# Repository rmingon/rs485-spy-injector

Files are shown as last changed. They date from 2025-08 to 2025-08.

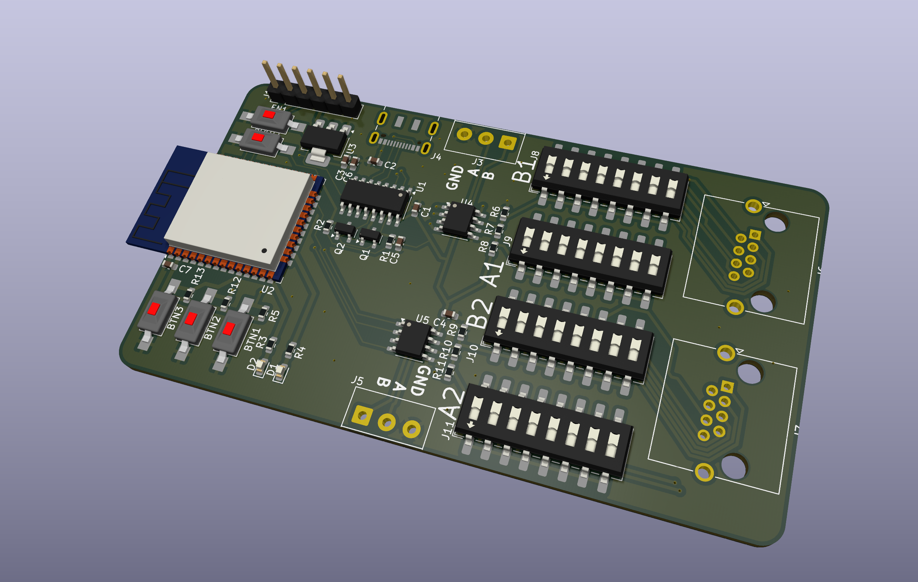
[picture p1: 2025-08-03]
3d.png

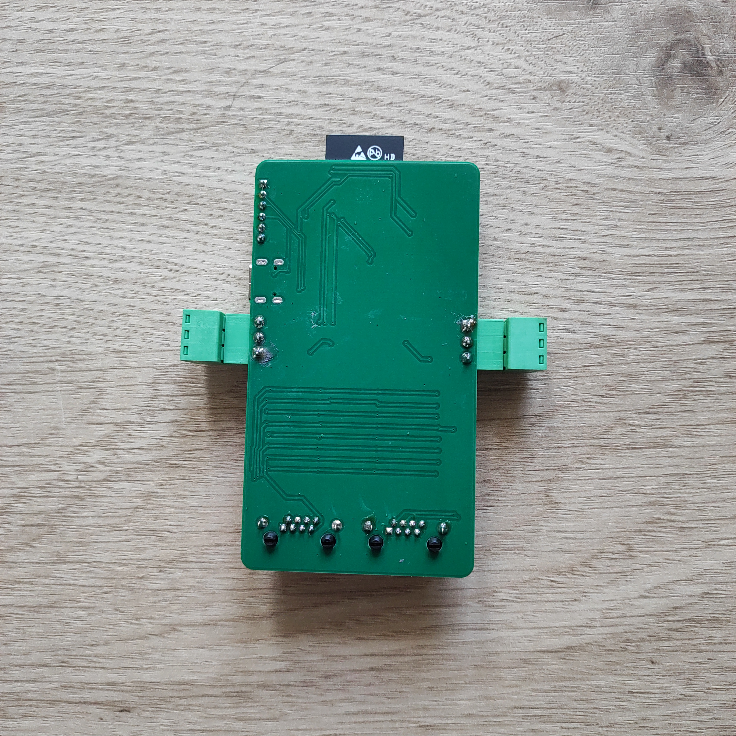
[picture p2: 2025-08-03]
back_pcb.jpg

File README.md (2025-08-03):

# ESP32 RS485 Hacker Suite

### _Sniff, Inject, and Control RS485 Communication from Your Phone_



## Overview

**ESP32 RS485 Hacker Suite** is a mobile-integrated toolkit built around the ESP32 microcontroller, designed to interact with RS485-based communication systems. This system allows for full control, inspection, and injection of RS485 traffic — making it a valuable asset for penetration testers, reverse engineers, and industrial system analysts.

## Features

- **RS485 Sniffing**  
  Monitor and log communication over RS485 in raw hex format. Useful for debugging, protocol analysis, or reverse engineering.

- **Hex Injection (Manual & Presets)**  
  Send custom hex data manually or use predefined presets. This supports use cases like device emulation, protocol fuzzing, or triggering specific system behaviors.

- **Mobile App Interface**  
  Control every feature directly from a smartphone via a dedicated app. Includes interfaces for configuration, command sending, and history review.

- **Dual RS485 Bus Support**  
  Work with two independent RS485 buses, ideal for simultaneously observing and injecting data into separate lines.

- **WiFi Configuration**  
  Easily connect your ESP32 to a local network or operate it in AP mode.

- **Command Presets**  
  Create and store frequently used hex commands for rapid execution.

- **Reception History**  
  View a log of all received data, enabling traffic inspection and replay.

## Ethical Hacking Applications

> **Important:** This tool is provided for **authorized use only**. Unauthorized access or tampering with industrial systems is illegal and unethical.

- Reverse engineering RS485-based protocols (MODBUS RTU, proprietary systems, etc.)
- Pen-testing building automation hardware (e.g., HVAC, elevator controllers, door access systems)
- Replay attacks or fault injection to test system resilience
- Simulating RS485 slave/master devices
- Forensic logging of unsecured RS485 data transmissions

## Hardware

- ESP32 (WROOM or S3 variant recommended)
- Dual RS485 transceivers (e.g., MAX485)
- Level shifters and protection diodes
- Power supply (USB or external)
- Custom PCB (designed in KiCad)

## Mobile App Overview

- Configure each RS485 bus individually
- Set baud rates and communication parameters
- Enter and send custom hex data manually
- Create named command presets (e.g., open door)
- View reception history for each bus

## Quick Example

```
Preset: Open door
Command: 09 21 32 AA B2
Target Device: Access Controller
Result: Relay Triggered, Door Unlocked
```

## Getting Started

### Flashing Firmware

1. Upload `main.cpp` to your ESP32 using Arduino IDE or PlatformIO.
2. Power on the device and connect via serial or mobile app.
3. Configure your RS485 settings and network preferences.

### Using the App

1. Connect to the ESP32 over WiFi.
2. Select Bus 1 or Bus 2.
3. Set the appropriate baud rate.
4. Send hex data manually or use a saved preset.
5. Monitor the reception log for data.

## Protocols Supported

- MODBUS RTU
- BACnet MS/TP (partial)
- Custom/Proprietary RS485 protocols
- Most serial-based building and industrial control protocols

## Disclaimer

This tool is meant for **educational, testing, and research** purposes only. Use it exclusively on systems you own or have explicit permission to test.

**You are fully responsible for how this tool is used. Unauthorized access or tampering with live systems can lead to legal consequences.**

5. **Use and Modify** the project under CERN-OHL v2 license.

## License

This project is licensed under the **CERN Open Hardware Licence Version 2**. See `LICENSE` file for full terms.

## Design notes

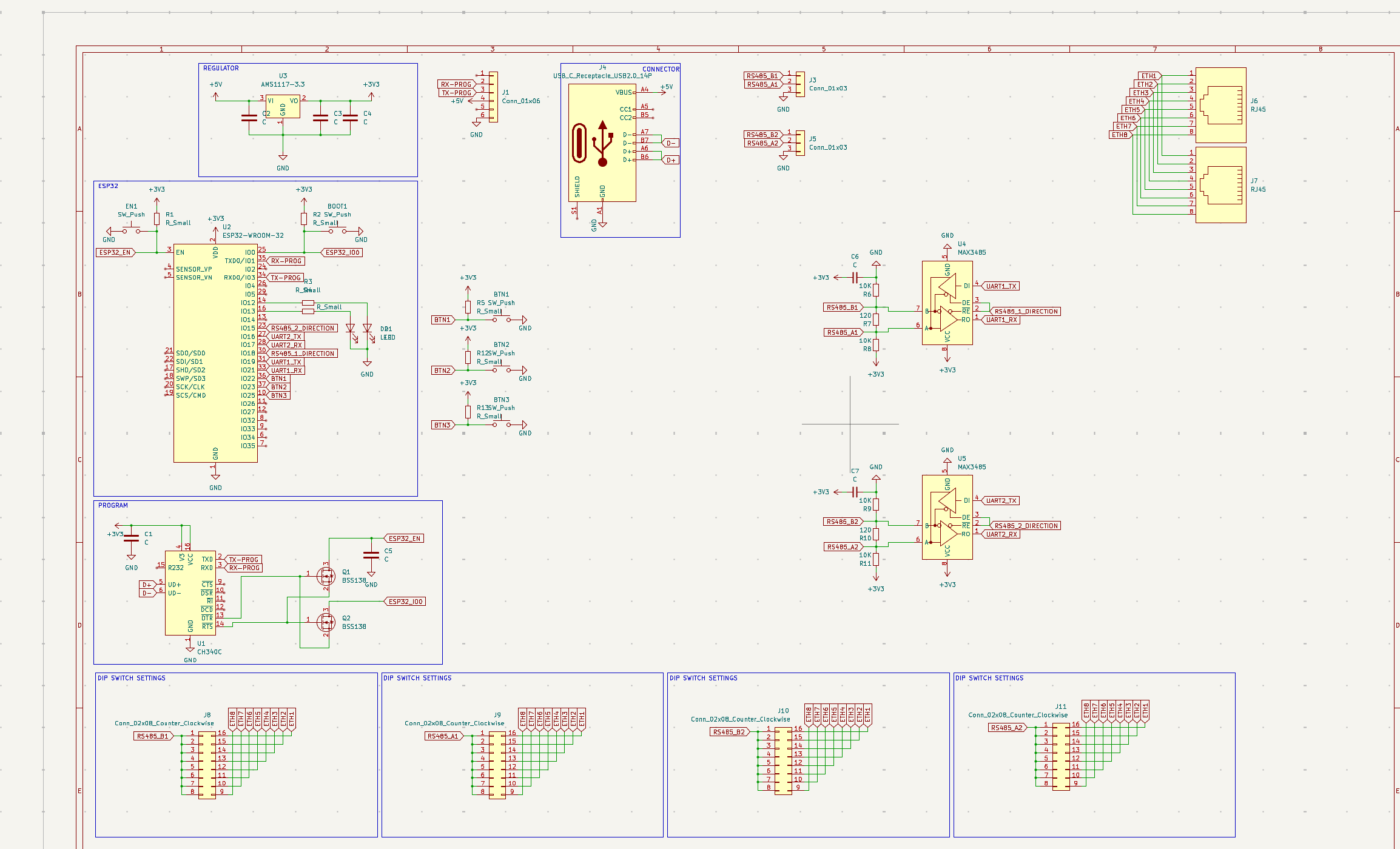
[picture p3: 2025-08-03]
schematic.png

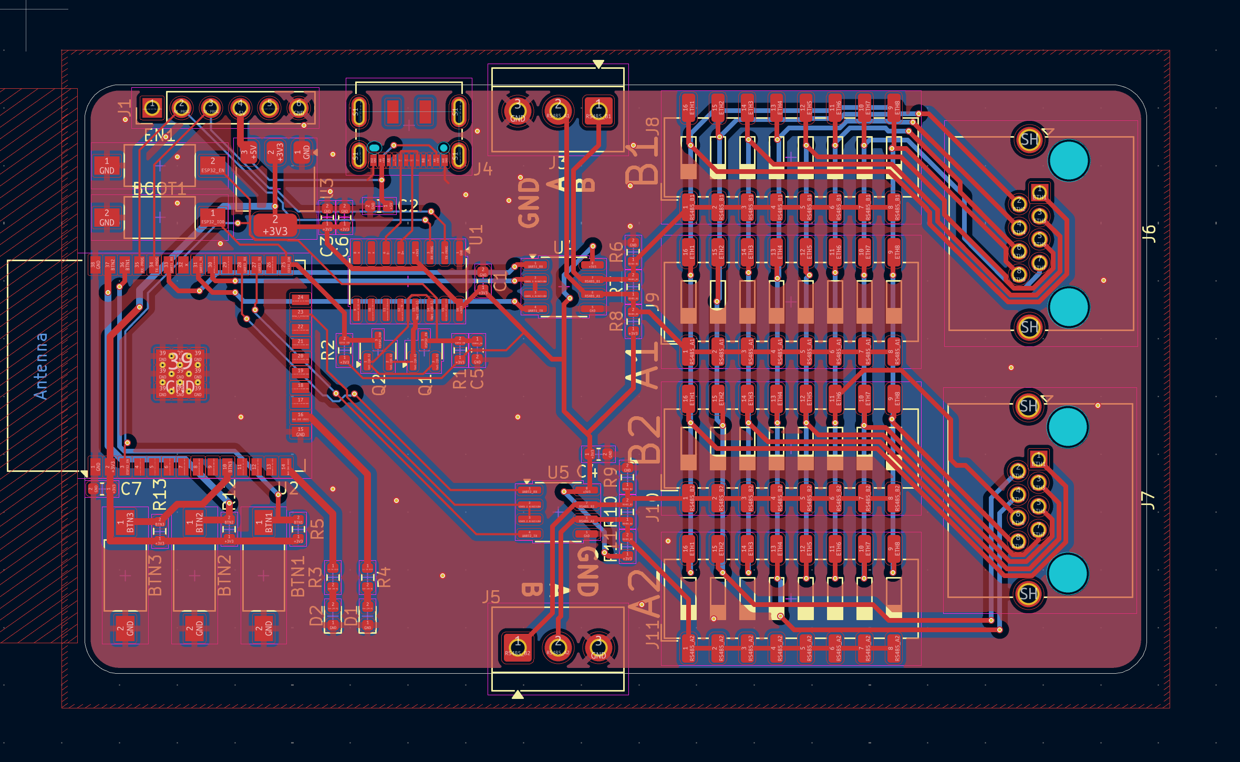
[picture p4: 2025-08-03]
pcb.png

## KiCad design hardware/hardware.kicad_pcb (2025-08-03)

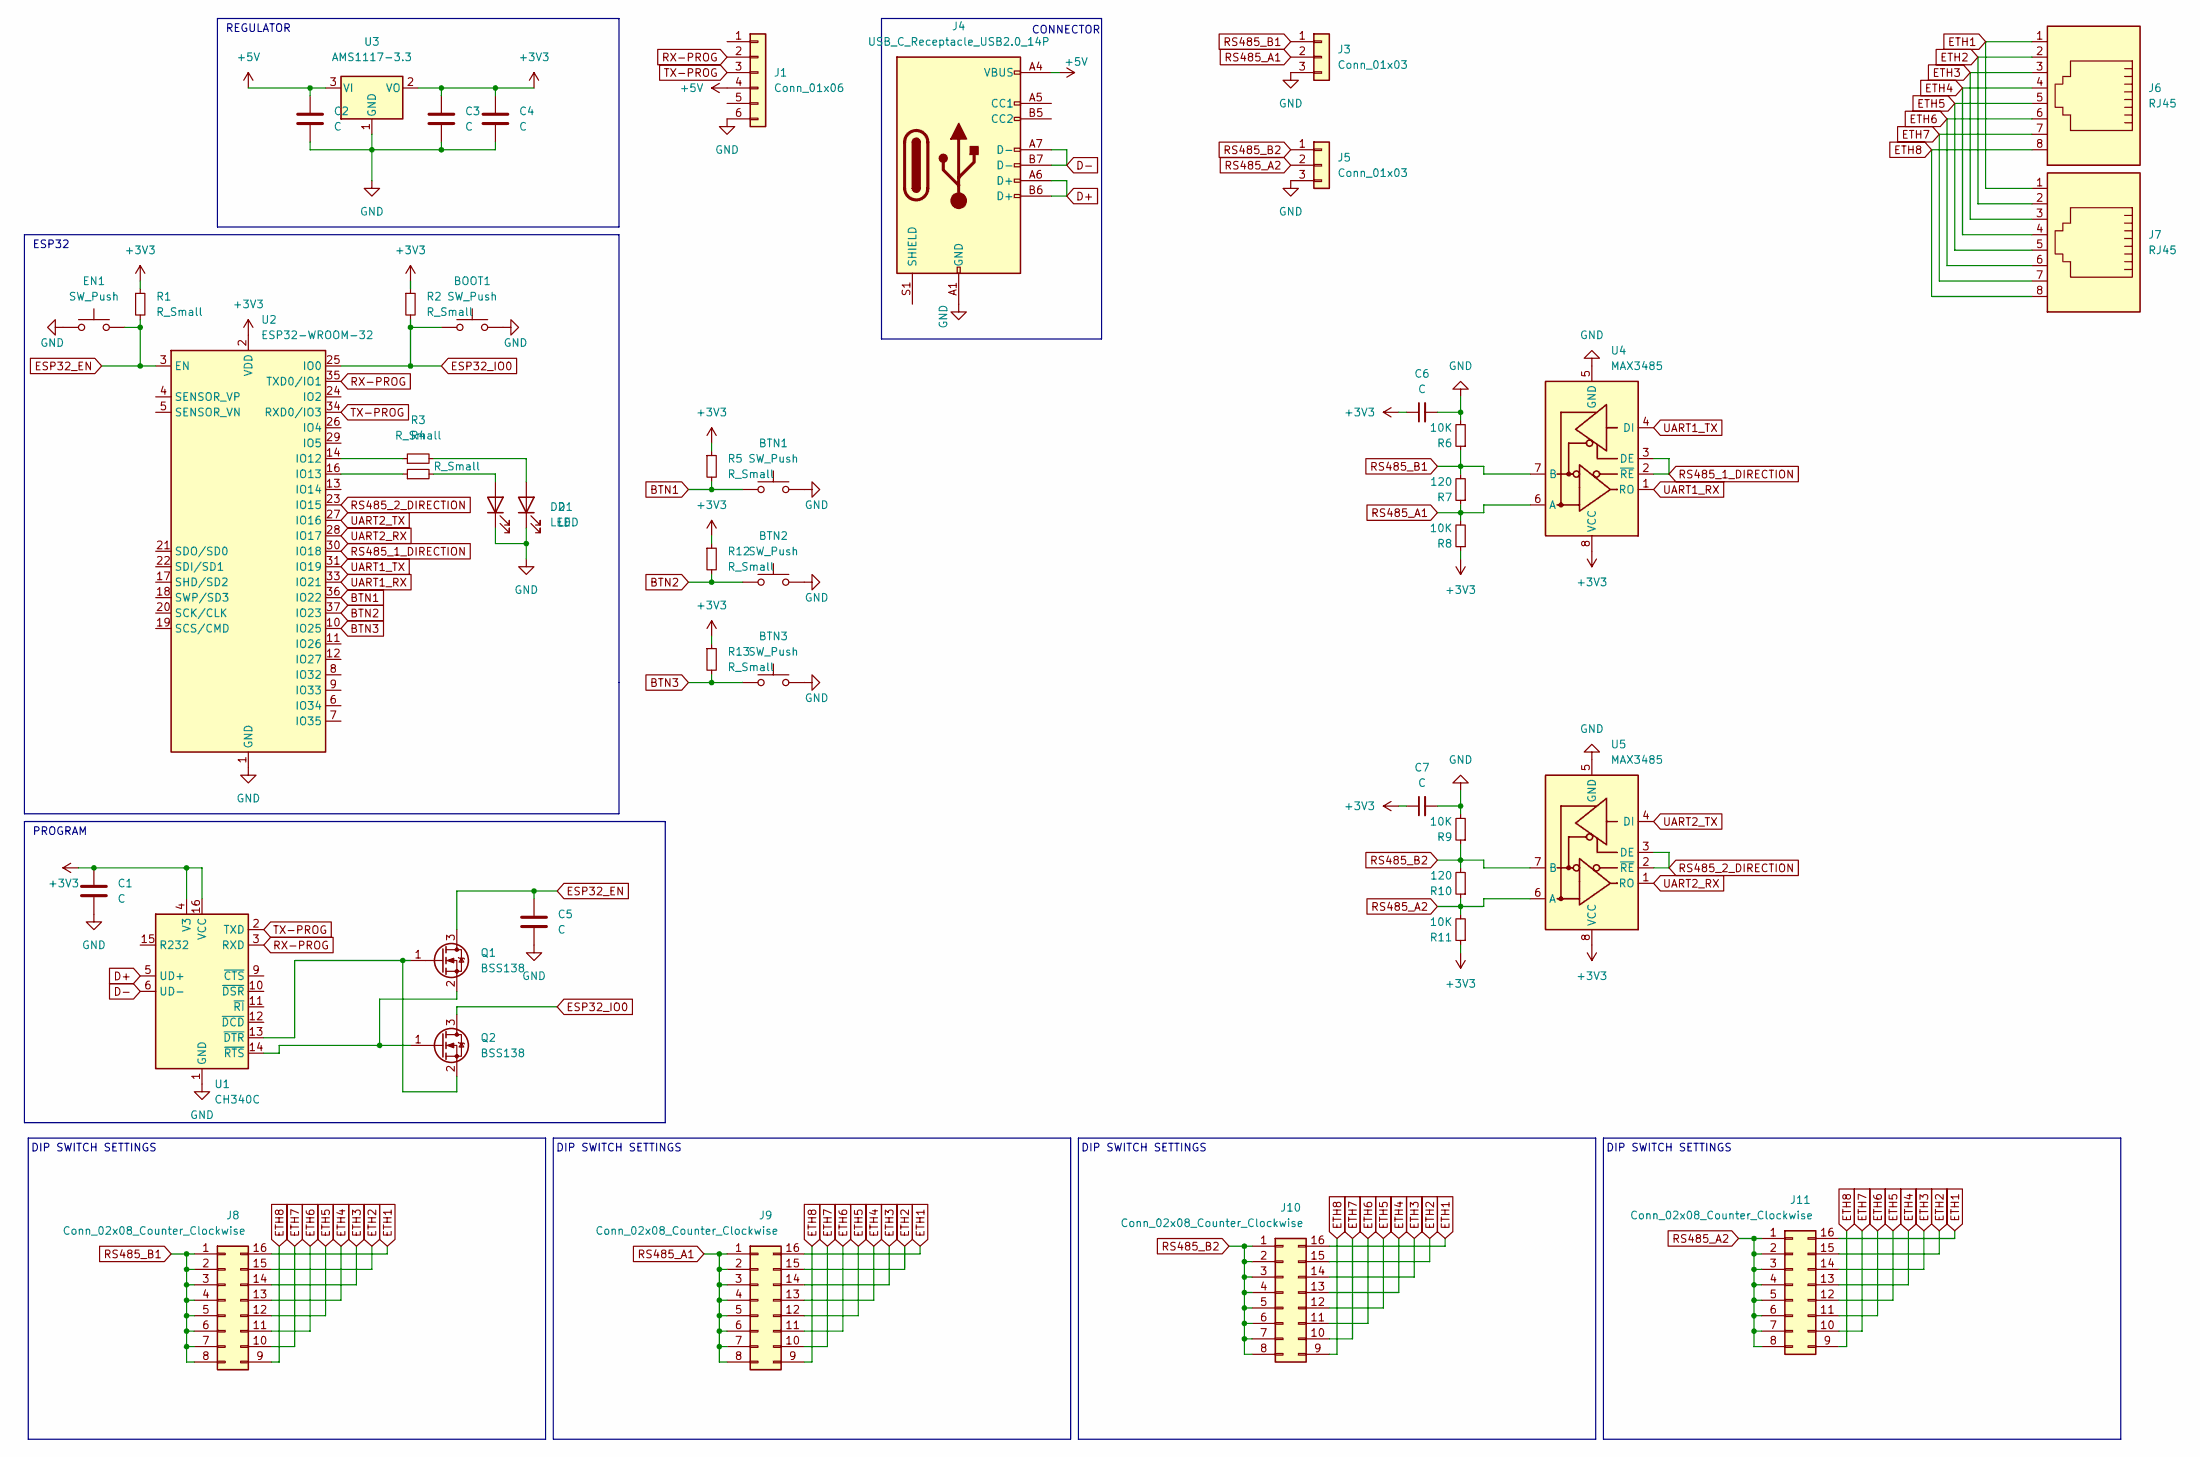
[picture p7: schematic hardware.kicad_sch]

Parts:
BOOT1: SW_Push; SW_SPST_FSMSM; LCSC C398053
BTN1, BTN2, BTN3: SW_Push; SW_SPST_FSMSM; LCSC C398053
C1, C2, C4: C; C_0603_1608Metric; LCSC C30926
C3, C5: C; C_0603_1608Metric; LCSC C19702
C6, C7: C; C_0603_1608Metric; LCSC C106245
D1: LED; LED_0603_1608Metric; LCSC C19171301
D2: LED; LED_0603_1608Metric; LCSC C434425
EN1: SW_Push; SW_SPST_FSMSM; LCSC C398053
J1: Conn_01x06; PinHeader_1x06_P2.54mm_Vertical
J3, J5: Conn_01x03; TerminalBlock_4Ucon_1x03_P3.50mm_Horizontal
J4: USB_C_Receptacle_USB2.0_14P; USB_C_Receptacle_JAE_DX07S016JA1R1500; LCSC C963213
J6, J7: RJ45; RJ45_Amphenol_RJHSE5380
J8, J9, J10, J11: Conn_02x08_Counter_Clockwise; SW_DIP_SPSTx08_Slide_6.7x21.88mm_W8.61mm_P2.54mm_LowProfile; LCSC C3293158
Q1, Q2: BSS138; SOT-23; LCSC C7420338
R1, R2, R5, R12, R13: R_Small; R_0603_1608Metric; LCSC C98220
R3, R4: R_Small; R_0603_1608Metric; LCSC C2906975
R6, R8, R9, R11: 10K; R_0603_1608Metric; LCSC C22975
R7, R10: 120; R_0603_1608Metric; LCSC C22975
U1: CH340C; SOIC-16_3.9x9.9mm_P1.27mm; LCSC C84681
U2: ESP32-WROOM-32; LCSC C82899
U3: AMS1117-3.3; SOT-223-3_TabPin2; LCSC C6186
U4, U5: MAX3485; SOIC-8_3.9x4.9mm_P1.27mm; LCSC C9943

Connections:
+3V3: C1.1, C3.1, C4.1, C6.1, C7.1, R1.1, R2.1, R5.1, R8.1, R11.1, R12.1, R13.1, U1.4 (V3), U1.16 (VCC), U2.2 (VDD), U3.2 (VO), U4.8 (VCC), U5.8 (VCC)
+5V: C2.1, J1.4, J4.A4 (VBUS), J4.A9 (VBUS), J4.B4 (VBUS), J4.B9 (VBUS), U3.3 (VI)
BTN1: BTN1.1, R5.2, U2.36 (IO22)
BTN2: BTN2.1, R12.2, U2.37 (IO23)
BTN3: BTN3.1, R13.2, U2.10 (IO25)
D+: J4.A6 (D+), J4.B6 (D+), U1.5 (UD+)
D-: J4.A7 (D-), J4.B7 (D-), U1.6 (UD-)
ESP32_EN: C5.1, EN1.2, Q1.3 (D), R1.2, U2.3 (EN)
ESP32_IO0: BOOT1.1, Q2.3 (D), R2.2, U2.25 (IO0)
ETH1: J6.1, J7.1, J8.16, J9.16, J10.16, J11.16
ETH2: J6.2, J7.2, J8.15, J9.15, J10.15, J11.15
ETH3: J6.3, J7.3, J8.14, J9.14, J10.14, J11.14
ETH4: J6.4, J7.4, J8.13, J9.13, J10.13, J11.13
ETH5: J6.5, J7.5, J8.12, J9.12, J10.12, J11.12
ETH6: J6.6, J7.6, J8.11, J9.11, J10.11, J11.11
ETH7: J6.7, J7.7, J8.10, J9.10, J10.10, J11.10
ETH8: J6.8, J7.8, J8.9, J9.9, J10.9, J11.9
GND: BOOT1.2, BTN1.2, BTN2.2, BTN3.2, C1.2, C2.2, C3.2, C4.2, C5.2, C6.2, C7.2, D1.1 (K), D2.1 (K), EN1.1, J1.6, J3.3, J4.A1 (GND), J4.A12 (GND), J4.B1 (GND), J4.B12 (GND), J5.3, R6.2, R9.2, U1.1 (GND), U2.1 (GND), U2.15 (GND), U2.38 (GND), U2.39 (GND), U3.1 (GND), U4.5 (GND), U5.5 (GND)
unnamed: D1.2 (A), R4.2
unnamed: D2.2 (A), R3.2
unnamed: Q1.1 (G), Q2.2 (S), U1.13 (~DTR)
unnamed: Q1.2 (S), Q2.1 (G), U1.14 (~RTS)
unnamed: R3.1, U2.14 (IO12)
unnamed: R4.1, U2.16 (IO13)
RS485_1_DIRECTION: U2.30 (IO18), U4.2 (~RE), U4.3 (DE)
RS485_2_DIRECTION: U2.23 (IO15), U5.2 (~RE), U5.3 (DE)
RS485_A1: J3.2, J9.1, J9.2, J9.3, J9.4, J9.5, J9.6, J9.7, J9.8, R7.1, R8.2, U4.6 (A)
RS485_A2: J5.2, J11.1, J11.2, J11.3, J11.4, J11.5, J11.6, J11.7, J11.8, R10.1, R11.2, U5.6 (A)
RS485_B1: J3.1, J8.1, J8.2, J8.3, J8.4, J8.5, J8.6, J8.7, J8.8, R6.1, R7.2, U4.7 (B)
RS485_B2: J5.1, J10.1, J10.2, J10.3, J10.4, J10.5, J10.6, J10.7, J10.8, R9.1, R10.2, U5.7 (B)
RX-PROG: J1.2, U1.3 (RXD), U2.35 (TXD0/IO1)
TX-PROG: J1.3, U1.2 (TXD), U2.34 (RXD0/IO3)
UART1_RX: U2.33 (IO21), U4.1 (RO)
UART1_TX: U2.31 (IO19), U4.4 (DI)
UART2_RX: U2.28 (IO17), U5.1 (RO)
UART2_TX: U2.27 (IO16), U5.4 (DI)

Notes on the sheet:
ESP32
CONNECTOR
DIP SWITCH SETTINGS
PROGRAM
REGULATOR

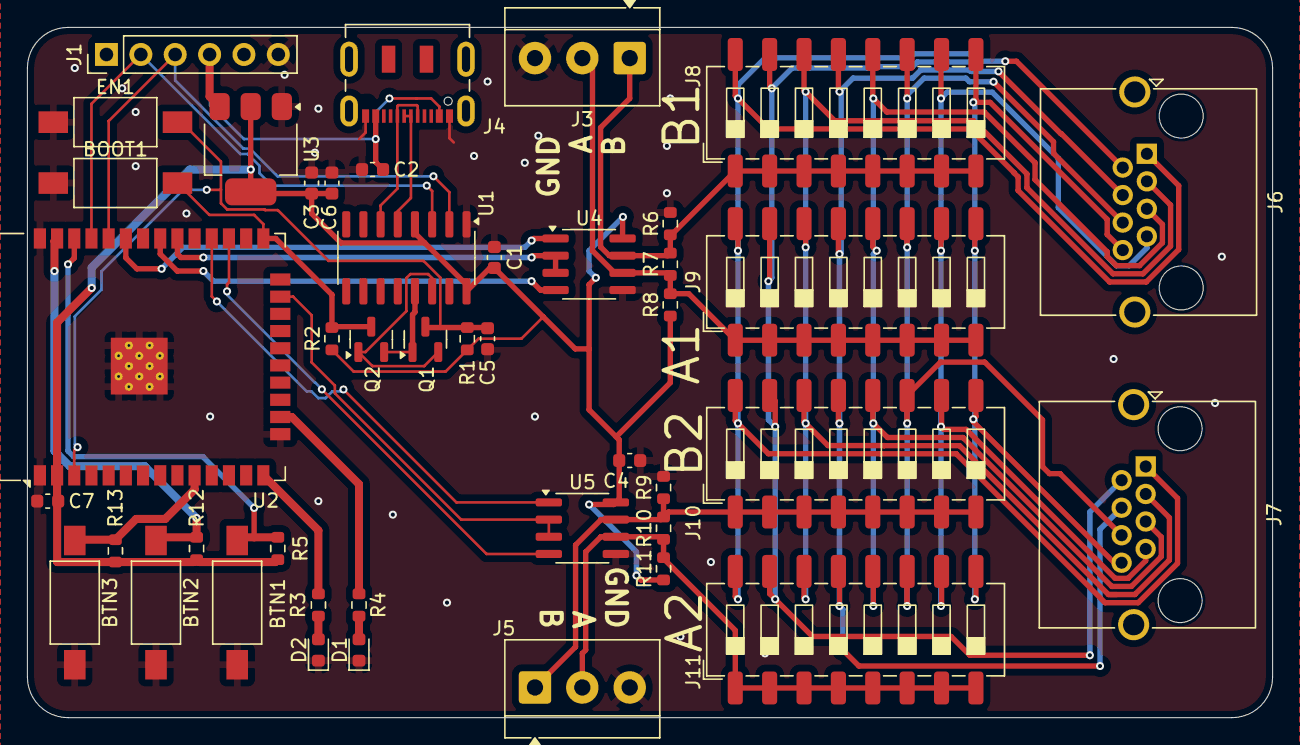
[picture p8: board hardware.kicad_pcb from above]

Board: 2 copper layers, 92.0 x 51.0 mm, 44 parts (0 on the bottom side), 36 nets.

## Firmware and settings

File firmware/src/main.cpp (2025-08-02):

#include <Arduino.h>
#include <ArduinoJson.h>
#include <BluetoothSerial.h>
#include <WiFi.h>
#include <vector>

static constexpr int UART1_RX = 21;
static constexpr int UART1_TX = 19;
static constexpr int UART2_RX = 17;
static constexpr int UART2_TX = 16;
static constexpr int RS485_DIR1 = 18;
static constexpr int RS485_DIR2 = 15;

static uint32_t UART1_BAUD = 115200;
static uint32_t UART2_BAUD = 115200;

BluetoothSerial SerialBT;

int tcpPort = 3333;
WiFiServer *tcpServer = nullptr;
WiFiClient tcpClient;

template <size_t N>
struct Ring
{
  volatile uint8_t buf[N];
  volatile size_t head = 0, tail = 0;
  volatile bool chunkReady = false;
  inline bool push(uint8_t b)
  {
    size_t n = (head + 1) % N;
    if (n == tail)
      return false; // Overflow
    buf[head] = b;
    head = n;
    return true;
  }
  size_t popMany(uint8_t *out, size_t maxBytes)
  {
    size_t cnt = 0;
    while (tail != head && cnt < maxBytes)
    {
      out[cnt++] = buf[tail];
      tail = (tail + 1) % N;
    }
    return cnt;
  }
  inline bool empty() const { return head == tail; }
};
static Ring<1024> rb1;
static Ring<1024> rb2;

static char btLine[512];
static size_t btLen = 0;
volatile bool btReady = false;
static char tcpLine[512];
static size_t tcpLen = 0;
volatile bool tcpReady = false;

static inline uint8_t hexVal(char c)
{
  if (c >= '0' && c <= '9')
    return c - '0';
  if (c >= 'a' && c <= 'f')
    return 10 + (c - 'a');
  if (c >= 'A' && c <= 'F')
    return 10 + (c - 'A');
  return 0xFF;
}
bool parseHexBytes(const char *s, std::vector<uint8_t> &out)
{
  uint8_t hn = 0xFF;
  for (; *s; ++s)
  {
    if (*s == ' ' || *s == ',' || *s == ':')
      continue;
    uint8_t v = hexVal(*s);
    if (v == 0xFF)
      continue;
    if (hn == 0xFF)
      hn = v;
    else
    {
      out.push_back((hn << 4) | v);
      hn = 0xFF;
    }
  }
  return hn == 0xFF;
}
String toHexLine(const uint8_t *data, size_t len)
{
  static const char *H = "0123456789ABCDEF";
  String s;
  s.reserve(len * 3);
  for (size_t i = 0; i < len; i++)
  {
    s += H[(data[i] >> 4) & 0xF];
    s += H[data[i] & 0xF];
    if (i + 1 < len)
      s += ' ';
  }
  return s;
}
void rs485SetDir(int pin, bool txOn) { digitalWrite(pin, txOn ? HIGH : LOW); }
void rs485Tx(int bus, const uint8_t *data, size_t len)
{
  HardwareSerial &U = (bus == 1) ? Serial1 : Serial2;
  int dirPin = (bus == 1) ? RS485_DIR1 : RS485_DIR2;
  rs485SetDir(dirPin, true);
  U.write(data, len);
  U.flush();
  rs485SetDir(dirPin, false);
}

void sendJsonToBT(const JsonDocument &d)
{
  serializeJson(d, SerialBT);
  SerialBT.print('\n');
}
void sendJsonToTCP(const JsonDocument &d)
{
  if (tcpClient && tcpClient.connected())
  {
    serializeJson(d, tcpClient);
    tcpClient.print('\n');
  }
}
void sendJsonToAll(const JsonDocument &d)
{
  sendJsonToBT(d);
  sendJsonToTCP(d);
}

void onUart1Rx()
{
  while (Serial1.available())
    rb1.push(Serial1.read());
  rb1.chunkReady = true;
}
void onUart2Rx()
{
  while (Serial2.available())
    rb2.push(Serial2.read());
  rb2.chunkReady = true;
}

void onBtData(const uint8_t *data, size_t len)
{
  for (size_t i = 0; i < len; i++)
  {
    if (btLen < sizeof(btLine) - 1)
      btLine[btLen++] = char(data[i]);
    if (data[i] == '\n')
    {
      btLine[btLen] = '\0';
      btReady = true;
    }
  }
}

bool wifiConnect(const char *ssid, const char *pwd, uint32_t timeoutMs = 8000)
{
  WiFi.mode(WIFI_STA);
  WiFi.begin(ssid, pwd);
  uint32_t t0 = millis();
  while (WiFi.status() != WL_CONNECTED && (millis() - t0) < timeoutMs)
  {
    delay(100);
  }
  return WiFi.status() == WL_CONNECTED;
}
void tcpStop()
{
  if (tcpClient)
  {
    tcpClient.stop();
  }
  if (tcpServer)
  {
    tcpServer->close();
    delete tcpServer;
    tcpServer = nullptr;
  }
}
bool tcpStart(int port)
{
  tcpStop();
  tcpServer = new WiFiServer(port);
  tcpServer->begin();
  return true;
}

void handleCommand(const JsonDocument &doc)
{
  if (doc.containsKey("bus") && (doc.containsKey("tx_hex") || doc.containsKey("baud")))
  {
    int bus = doc["bus"] | 1;
    if (doc.containsKey("baud"))
    {
      uint32_t baud = doc["baud"].as<uint32_t>();
      if (bus == 1)
      {
        UART1_BAUD = baud;
        Serial1.updateBaudRate(baud);
      }
      else
      {
        UART2_BAUD = baud;
        Serial2.updateBaudRate(baud);
      }
      StaticJsonDocument<128> r;
      r["ok"] = true;
      r["bus"] = bus;
      r["baud"] = baud;
      sendJsonToAll(r);
    }
    if (doc.containsKey("tx_hex"))
    {
      const char *txhex = doc["tx_hex"];
      std::vector<uint8_t> bytes;
      if (parseHexBytes(txhex, bytes) && !bytes.empty())
      {
        rs485Tx(bus, bytes.data(), bytes.size());
        StaticJsonDocument<192> r;
        r["ok"] = true;
        r["bus"] = bus;
        r["tx_hex"] = txhex;
        sendJsonToAll(r);
      }
      else
      {
        StaticJsonDocument<96> r;
        r["ok"] = false;
        r["err"] = "bad tx_hex";
        sendJsonToAll(r);
      }
    }
    return;
  }

  const char *cmd = doc["cmd"] | "";
  if (!strcmp(cmd, "wifi_connect"))
  {
    const char *ssid = doc["ssid"] | "";
    const char *pwd = doc["pwd"] | "";
    int port = doc["port"] | tcpPort;
    bool ok = wifiConnect(ssid, pwd, 8000);
    StaticJsonDocument<192> r;
    r["cmd"] = "wifi_connect";
    r["ok"] = ok;
    if (ok)
    {
      tcpPort = port;
      tcpStart(tcpPort);
      r["ip"] = WiFi.localIP().toString();
      r["port"] = tcpPort;
    }
    else
    {
      r["err"] = "wifi failed";
    }
    sendJsonToAll(r);
    return;
  }
  if (!strcmp(cmd, "wifi_status"))
  {
    StaticJsonDocument<192> r;
    r["cmd"] = "wifi_status";
    r["connected"] = (WiFi.status() == WL_CONNECTED);
    r["ip"] = WiFi.localIP().toString();
    r["rssi"] = (WiFi.status() == WL_CONNECTED) ? WiFi.RSSI() : 0;
    r["tcp"] = (tcpServer != nullptr);
    r["port"] = tcpPort;
    sendJsonToAll(r);
    return;
  }
  if (!strcmp(cmd, "wifi_disconnect"))
  {
    tcpStop();
    WiFi.disconnect(true, true);
    StaticJsonDocument<96> r;
    r["cmd"] = "wifi_disconnect";
    r["ok"] = true;
    sendJsonToAll(r);
    return;
  }
  if (!strcmp(cmd, "tcp_stop"))
  {
    tcpStop();
    StaticJsonDocument<96> r;
    r["cmd"] = "tcp_stop";
    r["ok"] = true;
    sendJsonToAll(r);
    return;
  }

  // IF command not exist
  StaticJsonDocument<96> r;
  r["ok"] = false;
  r["err"] = "unknown command";
  sendJsonToAll(r);
}

void setup()
{
  pinMode(RS485_DIR1, OUTPUT);
  digitalWrite(RS485_DIR1, LOW);
  pinMode(RS485_DIR2, OUTPUT);
  digitalWrite(RS485_DIR2, LOW);

  Serial.begin(115200);

  Serial1.begin(UART1_BAUD, SERIAL_8N1, UART1_RX, UART1_TX);
  Serial2.begin(UART2_BAUD, SERIAL_8N1, UART2_RX, UART2_TX);

  Serial1.setRxFIFOFull(1);
  Serial1.setRxTimeout(2);
  Serial2.setRxFIFOFull(1);
  Serial2.setRxTimeout(2);
  Serial1.onReceive(onUart1Rx, true);
  Serial2.onReceive(onUart2Rx, true);

  SerialBT.begin("ESP32-RS485-GW");
  SerialBT.onData(onBtData);

  Serial.println("RS485 <-> BT/TCP gateway ready. Use Bluetooth to configure Wi-Fi.");
}

void loop()
{
  if (rb1.chunkReady && !rb1.empty())
  {
    uint8_t tmp[512];
    noInterrupts();
    size_t n = rb1.popMany(tmp, sizeof(tmp));
    rb1.chunkReady = false;
    interrupts();
    if (n)
    {
      StaticJsonDocument<160> d;
      d["bus"] = 1;
      d["rx_hex"] = toHexLine(tmp, n);
      sendJsonToAll(d);
    }
  }

  if (rb2.chunkReady && !rb2.empty())
  {
    uint8_t tmp[512];
    noInterrupts();
    size_t n = rb2.popMany(tmp, sizeof(tmp));
    rb2.chunkReady = false;
    interrupts();
    if (n)
    {
      StaticJsonDocument<160> d;
      d["bus"] = 2;
      d["rx_hex"] = toHexLine(tmp, n);
      sendJsonToAll(d);
    }
  }

  if (tcpServer)
  {
    WiFiClient c = tcpServer->available();
    if (c)
    {
      if (tcpClient)
        tcpClient.stop();
      tcpClient = c;
      tcpClient.setNoDelay(true);
      StaticJsonDocument<96> d;
      d["event"] = "tcp_client_connected";
      sendJsonToAll(d);
    }
  }

  if (tcpClient && tcpClient.connected())
  {
    while (tcpClient.available())
    {
      int b = tcpClient.read();
      if (b < 0)
        break;
      if (tcpLen < sizeof(tcpLine) - 1)
        tcpLine[tcpLen++] = char(b);
      if (b == '\n')
      {
        tcpLine[tcpLen] = '\0';
        tcpReady = true;
      }
    }
  }

  if (btReady)
  {
    noInterrupts();
    String line(btLine);
    btLen = 0;
    btReady = false;
    interrupts();
    line.trim();
    if (line.length())
    {
      StaticJsonDocument<512> doc;
      DeserializationError err = deserializeJson(doc, line);
      if (!err)
        handleCommand(doc);
      else
      {
        StaticJsonDocument<128> r;
        r["ok"] = false;
        r["err"] = err.c_str();
        sendJsonToAll(r);
      }
    }
  }

  if (tcpReady)
  {
    noInterrupts();
    String line(tcpLine);
    tcpLen = 0;
    tcpReady = false;
    interrupts();
    line.trim();
    if (line.length())
    {
      StaticJsonDocument<512> doc;
      DeserializationError err = deserializeJson(doc, line);
      if (!err)
        handleCommand(doc);
      else
      {
        StaticJsonDocument<128> r;
        r["ok"] = false;
        r["err"] = err.c_str();
        sendJsonToAll(r);
      }
    }
  }
}

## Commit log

2025-07-19 add minimal schematic
    [hardware.kicad_pcb, hardware.kicad_sch]
2025-07-19 add pcb wiring
    [hardware.kicad_pcb, hardware.kicad_sch]
2025-07-20 rotation of ethernet connector
    [hardware.kicad_pcb]
2025-08-02 add gluestack
2025-08-03 add readme + pictures
    [bom.csv, designators.csv, hardware.kicad_pcb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]
2025-08-03 remove unused files
    [bom.csv, designators.csv, positions.csv]
